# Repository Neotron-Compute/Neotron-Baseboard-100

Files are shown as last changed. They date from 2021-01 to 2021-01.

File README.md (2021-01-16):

# Neotron-Baseboard-100

The Neotron Baseboard 100 is an micro-ATX Neotron motherboard, with Neotron CPU Socket and 4x Neotron Expansion Slots.

You must fit a Neotron CPU card for this board to function (or attach a microcontroller dev-kit of your choice using jumper wires).

### Audio Codec

* Texas Instruments TLV320AIC23B
  * I²S + I²C interface
  * Amplified 32mW headphone output and line out
  * Microphone in and line in
  * TSSOP-28 package
* Triple 3.5mm TRS jack (Kycon STX-4335-5BGP-S1)
  * Headphone Out (green)
  * Line In (blue)
  * Microphone In (pink)
* AC'97 Pin Header
  * Headphone Out
  * Microphone In
* Extra line-level output pin header (e.g. for additional RCA audio jacks - operates in addition to 3.5mm headphone jack output)
* Internal line-level input pin header (e.g. for CD-ROM audio - disabled when line-in 3.5mm jack in-use)

### Super VGA output

* 15-pin D-Sub VGA interface
* 18-bit (6-6-6) RGB R2R DAC
* 3peak TPF133A or Texas Instruments THS7316 RGB video buffer
   * 36 MHz bandwidth - 1024x768@60Hz maximum
   * 6dB gain
   * Drives 75 ohm standard VGA interface
* I²C/DDC level shifter and EMC filter

### RS232 Interface

* Tx, Rx, RTS and CTS signals
* 3.3V TTL on the MCU side
* RS-232 signalling on a 9-pin D-Sub connector (or 10-pin IDC box header), wired DTE

### Board Management Controller

* ST Micro STM32F0 (STM32F030F4P6) microcontroller
  * 32-bit Arm Cortex-M0+ Core
  * 3.3V I/O
  * 8 KiB Flash
  * 4 KiB SRAM
  * TSSOP-20 package
* Controls two PS/2 ports
* Monitors 5V and 3.3V rails
* Controls system reset, soft-on and soft-off for main CPU
* Can the main 5V regulator on and off
* Runs from 3.3V stand-by regulator
* I²C interface (with dedicated IRQ line) with main CPU

| Pin | Name  | Peripheral | Function |
|:----|:---|:---|:---|
| 16  | VDD | N/A | 3.3V Digital Power |
| 5 | VDDA  | N/A | 3.3V Analog Power  |
| 15  | VSS | N/A | Ground |
| 1 | BOOT0 | BOOT0 | Boot Mode Select |
| 4 | NRST  | Reset | Reset BMC |
| 6 | PA0 | ADC0 | Monitor 3.3V rail  |
| 7 | PA1 | ADC0 | Monitor 5V rail |
| 8 | PA2 | USART1_TX  | Debug Log |
| 9 | PA3 | Output | Status LED |
| 10  | PA4 | Output | DC-DC Enable |
| 11  | PA5 | Output | System Reset |
| 12  | PA6 | Input | Reset Switch In |
| 13  | PA7 | Input | Power Switch In |
| 17  | PA9 | I2C0_SCL | Host comms |
| 18  | PA10  | I2C0_SDA | Host comms |
| 19  | PA13  | IO | PS/2 Data 1 |
| 20  | PA14  | IO | PS/2 Clock 1 |
| 14  | PB1 | Output | Host IRQ |
| 2 | PF0 | IO | PS/2 Data 0 |
| 3 | PF1 | IO | PS/2 Clock 0 |

### PS/2 Keyboard and Mouse

* Twin mini 6-pin DIN ports
* Controlled via Board Management Controller

### Power Supply

* Unregulated 12V (8V to 28V) input fused with a PTC at 2A
* 3A 5.0V main regulator (DC-DC switch-mode regulator module)
* 30mA 3.3V stand-by regulator (a micropower linear regulator)
* 1A 3.3V regulator (a high-power 1117 type linear regulator)
* Controlled by the Board Management Controller

### CPU Socket

The CPU can either be designed to solder direct to your particular motherboard design, or it can be fitted to a second PCB 'CPU card' which plugs into a socket on the motherboard. We have designed a special 80-pin socket pinout, which provides all the signals for required for the standard peripherals available in this design.

The socket is basically two 2x20 pin headers, placed 130 mil apart. This should give enough space to fit even a TQFP-176 microcontroller and some TSOP-54 SDRAM.

The pins are labelled in row.column fashion, i.e. 1.1 is top left, 1.20 is top right and 4.20 is bottom right.

```
 +----- Pin 1.1
 |
 v
+---------------------------------------+
|o o o o o o o o o o o o o o o o o o o o|
|o o o o o o o o o o o o o o o o o o o o|
+---------------------------------------+

+---------------------------------------+
|o o o o o o o o o o o o o o o o o o o o|
|o o o o o o o o o o o o o o o o o o o o|
+---------------------------------------+
                                       ^
                                       |
                         Pin 4.20 -----+
```

| Pin  | Function |
|:-----|:---|
| 1.1  | VGA_RED5 |
| 1.2  | VGA_RED4 |
| 1.3  | VGA_RED3 |
| 1.4  | VGA_RED2 |
| 1.5  | VGA_RED1 |
| 1.6  | VGA_RED0 |
| 1.7  | VGA_GREEN5 |
| 1.8  | VGA_GREEN4 |
| 1.9  | VGA_GREEN3 |
| 1.10 | VGA_GREEN2 |
| 1.11 | VGA_GREEN1 |
| 1.12 | VGA_GREEN0 |
| 1.13 | VGA_BLUE5 |
| 1.14 | VGA_BLUE4 |
| 1.15 | VGA_BLUE3 |
| 1.16 | VGA_BLUE2 |
| 1.17 | VGA_BLUE1 |
| 1.18 | VGA_BLUE0 |
| 1.19 | VGA_HSYNC |
| 1.20 | VGA_VSYNC |
| 2.1  | VGA_DDC_SDA |
| 2.2  | VGA_DDC_SCL |
| 2.3  | UART_RX |
| 2.4  | UART_TX |
| 2.7  | 3V3 |
| 2.8  | 3V3 |
| 2.9  | 3V3 |
| 2.10 | GND |
| 2.11 | GND |
| 2.12 | GND |
| 2.13 | AUDIO_BCLK_TO_CODEC  |
| 2.14 | AUDIO_DAT_TO_CODEC |
| 2.15 | AUDIO_LR_TO_CODEC |
| 2.16 | AUDIO_DAT_FROM_CODEC |
| 2.17 | AUDIO_LR_FROM_CODEC  |
| 2.18 | USB_EN |
| 2.19 | USB_D- |
| 2.20 | USB_D+ |
| 3.1  | I2C_SDA |
| 3.2  | I2C_SCL |
| 3.3  | UART_CTS |
| 3.4  | UART_RTS |
| 3.7  | GND |
| 3.8  | GND |
| 3.9  | GND |
| 3.10 | 5V |
| 3.11 | 5V |
| 3.12 | 5V |
| 3.13 | ~SPI_CS7 |
| 3.14 | ~SPI_CS6 |
| 3.15 | ~SPI_CS5 |
| 3.16 | ~SPI_CS4 |
| 3.17 | ~SPI_CS3 |
| 3.18 | ~SPI_CS2 |
| 3.19 | ~SPI_CS1 |
| 3.20 | ~SPI_CS0 |
| 4.1  | ~SDMMC_CARD_DETECT |
| 4.2  | ~SDMMC_WRITE_PROT |
| 4.3  | SDMMC_DAT2 |
| 4.4  | SDMMC_DAT3 |
| 4.5  | SDMMC_CMD |
| 4.6  | SDMMC_CLK |
| 4.7  | SDMMC_DAT0 |
| 4.8  | SDMMC_DAT1 |
| 4.9  | SPI_COPI |
| 4.10 | SPI_CIPO |
| 4.11 | SPI_CLK |
| 4.12 | ~RESET |
| 4.13 | ~IRQ7 |
| 4.14 | ~IRQ6 |
| 4.15 | ~IRQ5 |
| 4.16 | ~IRQ4 |
| 4.17 | ~IRQ3 |
| 4.18 | ~IRQ2 |
| 4.19 | ~IRQ1 |
| 4.20 | ~IRQ0 |

## Expansion

The (up-to) seven expansion sockets allow you to add on I²C or SPI based devices at a later date. Each provides a single chip-select and a single IRQ line - the motherboard design should ensure each socket gets a unique signal for each of these. Each expansion device should also contain a AT24C256 or similar EEPROM device. To allow these EEPROM devices to be scanned, each slot also contains three `EEPROM_ADDRESS` pins, tied to Vcc or GND in a unique combination. These should be connected through to the EEPROM address lines on your AT24C256, thus ensuring that each expansion card has its EEPROM at a unique address - 0x50 on Slot 0 through to a maximum possible 0x57 for Slot 7. Where your board has on-board devices, you should fit an AT24C256 EEPROM for each device so that the on-board devices can be discovered, exactly as if they were on an expansion card.

The expansion slot is a simple 2x10 header. We suggest the use of a TE card-edge connector, but you could equally use two 1x10 pin-headers if desired.

The pin functions are:

```
     SPI_COPI   1    2   GND
     SPI_CIPO   3    4   GND
      SPI_CLK   5    6   GND
      ~SPI_CS   7    8   ~IRQ
      I2C_SDA   9   10   I2C_SCL
 EEPROM_ADDR0   11  12   EEPROM_ADDR1
 EEPROM_ADDR2   13  14   ~RESET
           5V   15  16   5V
          3V3   17  18   3V3
          GND   19  20   GND
```

## Expansion Ideas

Why not design and build your own expansion card? You could try designing:

* A dual Atari/SEGA 9-pin Joypad Interface
* An Ethernet card, e.g. with an ENC28J60 SPI/Ethernet interface IC
* A Mikro Eletronika Click adaptor, allow many of the range of [Click board](https://www.mikroe.com/click) to be fitted
* A Wi-Fi/Bluetooth card, using an Espressif ESP32
* A second processor card - perhaps with a RISC-V microcontroller, or classic Zilog Z80
* An OPL2 or OPL3 based FM synthesiser card
* An ISA adaptor card (taking an ISA card at right-angles, i.e. parallel to the base board) - a simple microcontroller should be able to bit-bang the ISA bus at 8 MHz and offer an SPI peripheral interface to the Neotron Expansion Slot
* An IDE interface card, allowing 40-pin IDE Hard Disk Drives and CD-ROM drives to be used - this will be quite similar to an ISA bus adaptor
* A floppy drive controller card - either using an eSPI Super I/O chip, or connecting a legacy ISA bus floppy controller as per the ISA adaptor
* A video card for a second monitor output, perhaps based on the CPLD used in the [VGAtonic](https://hackaday.io/project/6309-vga-graphics-over-spi-and-serial-vgatonic)

## Changelog

See [CHANGELOG.md](./CHANGELOG.md) for a list of detailed changes.

## Licence

This schematic and PCB design is Copyright (c) The Neotron Developers.



This work is licensed under a [Creative Commons Attribution-ShareAlike 4.0 International License](http://creativecommons.org/licenses/by-sa/4.0/).

## Contribution Agreement

Unless you explicitly state otherwise, any contribution intentionally submitted for inclusion in the work by you, as defined in the Apache-2.0 license, shall be licensed as above, without any additional terms or conditions.

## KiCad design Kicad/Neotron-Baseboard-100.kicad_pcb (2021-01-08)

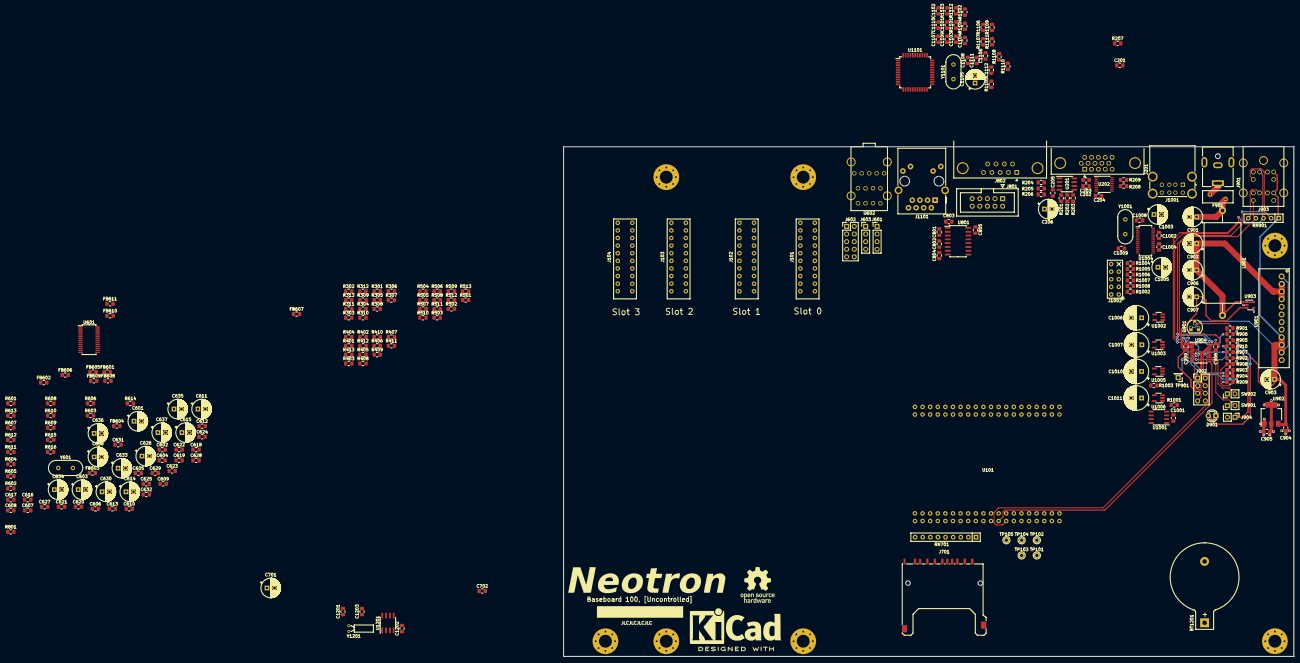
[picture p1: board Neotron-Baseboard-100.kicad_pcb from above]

Board: 4 copper layers, 243.8 x 170.2 mm, 257 parts (0 on the bottom side), 218 nets.

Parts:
BT1201: Coin Cell; BatteryHolder_Keystone_103_1x20mm
C201: 220n; C_0805_2012Metric_Pad1.15x1.40mm_HandSolder
C202, C203, C204, C205, C602, C604, C612, C613, C627, C702, C801, C802, C803, C804, C805, C904, C908, C909, C1001, C1002, C1004, C1106, C1107, C1108, C1109, C1110, C1201: 100n; C_0805_2012Metric_Pad1.15x1.40mm_HandSolder
C206, C601, C603, C611, C626, C633, C634, C635, C636, C637, C638, C701: 10u; CP_Radial_D6.3mm_P2.50mm
C605, C606, C620, C621: 470n; C_0805_2012Metric_Pad1.15x1.40mm_HandSolder
C607, C608, C609, C610, C616, C617, C618, C619, C622, C623, C624, C625, C632: DNF; C_0805_2012Metric_Pad1.15x1.40mm_HandSolder
C614, C615: 220u; CP_Radial_D6.3mm_P2.50mm
C628, C629: 22p; C_0805_2012Metric_Pad1.15x1.40mm_HandSolder
C630: 1u; CP_Radial_D6.3mm_P2.50mm
C631: 47p; C_0805_2012Metric_Pad1.15x1.40mm_HandSolder
C901, C902: 100u 50V; CP_Radial_D6.3mm_P2.50mm
C903: 22u; CP_Radial_D6.3mm_P2.50mm
C905: 1u; C_0805_2012Metric_Pad1.15x1.40mm_HandSolder
C906: 1u 50V; CP_Radial_D6.3mm_P2.50mm
C907, C1003, C1005: 4u7; CP_Radial_D6.3mm_P2.50mm
C1006, C1007, C1010, C1011: 120u; CP_Radial_D8.0mm_P3.50mm
C1008, C1009, C1103, C1104: 12p; C_0805_2012Metric_Pad1.15x1.40mm_HandSolder
C1101, C1102: 10n; C_0805_2012Metric_Pad1.15x1.40mm_HandSolder
C1105: 10u Low ESR; CP_Radial_D6.3mm_P2.50mm
C1111, C1112: 1n; C_0805_2012Metric_Pad1.15x1.40mm_HandSolder
C1202, C1203: 6p; C_0805_2012Metric_Pad1.15x1.40mm_HandSolder
D901: LED; LED_D3.0mm
F901: 32V 2A PTC; Fuse_BelFuse_0ZRE0016FF_L9.9mm_W3.8mm
FB601, FB602, FB603, FB604, FB605, FB606, FB608, FB609, FB610, FB611: 220R@100MHz; L_0805_2012Metric_Pad1.15x1.40mm_HandSolder
FB607: 600R@100MHz; L_0805_2012Metric_Pad1.15x1.40mm_HandSolder
H101, H102, H103, H104, H105, H106, H107: MountingHole_Pad; MountingHole_4.3mm_M4_Pad_Via
J101, J102, J103, J104: Neotron-Expansion-Slot
J201: DE15HD; DSUB-15-HD_Female_Horizontal_P2.29x1.98mm_EdgePinOffset3.03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
J601: Line Out; PinHeader_1x04_P2.54mm_Vertical
J602: AC'97 Audio Header; PinHeader_2x05_P2.54mm_Vertical
J603: CD Audio In; PinHeader_1x04_P2.54mm_Vertical
J701: SD_Card; SD_Kyocera_145638009211859+
J801: Conn_02x05; IDC-Header_2x05_P2.54mm_Vertical
J802: DB9_Male_MountingHoles; DSUB-9_Male_Horizontal_P2.77x2.84mm_EdgePinOffset7.70mm_Hou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
J901: Jack-DC; BarrelJack_CUI_PJ-063AH_Horizontal
J902: Conn_02x04_Odd_Even; PinHeader_2x04_P2.54mm_Vertical
J903: Double-mini-DIN-6; Double_mini-DIN_6
J904: Header; PinHeader_1x02_P2.54mm_Vertical
J1001: USB Ports External; CUI_UJ2-ADH-1-TH
J1002: USB Ports Internal; USB_Header
J1101: RJ45 MagJack; RJ45_Amphenol_RJMG1BD3B8K1ANR
L901: 22uH 6A; L_Axial_L26.7mm_D12.1mm_P35.00mm_Horizontal_Vishay_IHA-103
LOGO101: Neotron Logo; logo
LOGO102: Kicad Logo; KiCad-Logo2_12mm_SilkScreen
LOGO103: OSHW Logo; OSHW-Logo_11.4x12mm_SilkScreen
Q901: BC548; TO-92_HandSolder
R201, R202, R203: 75; R_0805_2012Metric_Pad1.15x1.40mm_HandSolder
R204, R205, R206, R613, R902, R903, R904, R906, R907, R908, R909, R1001, R1003, R1004, R1005, R1006, R1007, R1008: 10k; R_0805_2012Metric_Pad1.15x1.40mm_HandSolder
R207, R801, R1110: DNF; R_0805_2012Metric_Pad1.15x1.40mm_HandSolder
R208, R209: 1k5; R_0805_2012Metric_Pad1.15x1.40mm_HandSolder
R301, R302, R303, R304, R305, R306, R312, R401, R402, R403, R404, R405, R406, R412, R501, R502, R503, R504, R505, R506, R512: 24k 0.5%; R_0805_2012Metric_Pad1.15x1.40mm_HandSolder
R307, R308, R309, R310, R311, R407, R408, R409, R410, R411, R507, R508, R509, R510, R511: 12k 0.5%; R_0805_2012Metric_Pad1.15x1.40mm_HandSolder
R313, R413, R513: 3300; R_0805_2012Metric_Pad1.15x1.40mm_HandSolder
R601, R602: 100; R_0805_2012Metric_Pad1.15x1.40mm_HandSolder
R603, R604, R605, R606: 47k; R_0805_2012Metric_Pad1.15x1.40mm_HandSolder
R607, R608, R609, R610, R612: 4k7; R_0805_2012Metric_Pad1.15x1.40mm_HandSolder
R611: 2k2; R_0805_2012Metric_Pad1.15x1.40mm_HandSolder
R614, R615, R616: 2R2; R_0805_2012Metric_Pad1.15x1.40mm_HandSolder
R901: 2k; R_0805_2012Metric_Pad1.15x1.40mm_HandSolder
R905, R910: 1k; R_0805_2012Metric_Pad1.15x1.40mm_HandSolder
R1002: 2k7 1%; R_0805_2012Metric_Pad1.15x1.40mm_HandSolder
R1101, R1103, R1104, R1107: 49R9 1%; R_0805_2012Metric_Pad1.15x1.40mm_HandSolder
R1102, R1106: 10; R_0805_2012Metric_Pad1.15x1.40mm_HandSolder
R1105: 100k; R_0805_2012Metric_Pad1.15x1.40mm_HandSolder
R1108, R1109: 180; R_0805_2012Metric_Pad1.15x1.40mm_HandSolder
R1111: 1M; R_0805_2012Metric_Pad1.15x1.40mm_HandSolder
R1112: 12k4 1%; R_0805_2012Metric_Pad1.15x1.40mm_HandSolder
RN701: 8x10k; R_Array_SIP9
RN901: 2k7 x 4; R_Array_SIP5
SW901, SW902: SW_DIP_x01; PinHeader_1x02_P2.54mm_Vertical
TP101, TP102, TP103, TP104, TP105: TestPoint; TestPoint_THTPad_D2.0mm_Drill1.0mm
TP901: TestPoint; PinHeader_1x01_P2.54mm_Vertical
U101: Neotron-CPU; Neotron_CPU_Socket
U201: THS7316; SOIC-8_3.9x4.9mm_P1.27mm
U202: TPD7S019; SSOP-16_3.9x4.9mm_P0.635mm
U601: TLV320AIC23BPW; TSSOP-28_4.4x9.7mm_P0.65mm
U602: STX-4335-5BGP-S1
U801: ST3232CDR; SO-16_5.3x10.2mm_P1.27mm
U901: 5V DC-DC Module; K78xx-3AR3
U902: TLV1117 3.3V 1A; SOT-223-3_TabPin2
U903: MAX1615; SOT-23-5
U904: STM32F030F4Px; TSSOP-20_4.4x6.5mm_P0.65mm
U1001: AP2501; SO-8_3.9x4.9mm_P1.27mm
U1002, U1003, U1005, U1006: MIC2005A-2YM5; SOT-23-5_HandSoldering
U1004: XR22404CG28; SSOP-28_3.9x9.9mm_P0.635mm
U1101: ENC424J600; TQFP-44_10x10mm_P0.8mm
U1201: MCP7940; SOIC-8_3.9x4.9mm_P1.27mm
Y601, Y1001: 12M; Crystal_HC49-4H_Vertical
Y1101: 25M; Crystal_HC49-4H_Vertical
Y1201: 32,768 Hz; Crystal_DS26_D2.0mm_L6.0mm_Horizontal

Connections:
+3.3VP: C907.1, C908.1, C909.1, J902.5, U903.3, U904.5, U904.16
+3V3: C204.2, C205.2, C206.2, C701.1, C702.1, C805.2, C905.1, C1106.1, C1107.1, C1108.1, C1109.1, C1110.1, C1111.1, C1112.1, C1201.1, FB608.2, FB610.2, J101.17, J101.18, J102.11, J102.17, J102.18, J103.12, J103.17, J103.18, J104.11, J104.12, J104.17, J104.18, J701.4, R908.1, R1001.1, R1003.1, R1101.2, R1102.1, R1103.1, R1104.2, R1105.1, R1106.1, R1107.1, RN701.1, U101.2.7, U101.2.8, U101.2.9, U201.4, U202.7, U801.16, U902.2, U1101.4, U1101.12, U1101.15, U1101.18, U1101.44, U1201.8
+5V: C202.2, C203.2, C903.1, C904.1, C1001.1, FB609.2, J101.15, J101.16, J102.15, J102.16, J103.15, J103.16, J104.15, J104.16, J201.9, J903.4, J903.10, R208.1, R209.1, R902.1, RN901.1, U101.3.10, U101.3.11, U101.3.12, U202.1, U202.2, U901.4, U902.3, U1001.2, U1001.3
+BATT: BT1201.1, U1201.3
/Audio/3V3_ANALOG: C601.1, C602.1, C603.1, C604.1, C634.1, R614.1, U601.8, U601.14
/Audio/3V3_DIGITAL: C611.1, C612.1, C613.1, C638.1, R616.1, U601.1, U601.27
/Audio/5V0_ANALOG: C636.1, J602.7, R615.1
/Audio/AUDIO_BIT_CLK_TO_CODEC: U101.2.13, U601.3
/Audio/AUDIO_DAT_FROM_CODEC: U101.2.16, U601.6
/Audio/AUDIO_DAT_TO_CODEC: U101.2.14, U601.4
/Audio/AUDIO_LR_FROM_CODEC: U101.2.17, U601.7
/Audio/AUDIO_LR_TO_CODEC: U101.2.15, U601.5
/Audio/BIASOUT: R611.2, U601.17
/Audio/CDInL: J603.1, U602.34
/Audio/CDInR: J603.4, U602.33
/Audio/FrontHPL: C617.2, FB603.1, J602.9
/Audio/FrontHPR: C619.2, FB604.1, J602.5
/Audio/FrontMicL: J602.1, U602.4
/Audio/FrontMicR: J602.3, U602.3
/Audio/LineL: C608.2, FB601.1, J601.1
/Audio/LineR: C610.2, FB602.1, J601.4
/Audio/MICIN: R612.1, U601.18
/Audio/RearHPL: J602.10, U602.25
/Audio/RearHPR: J602.6, U602.22
/Audio/RearInL: C623.2, FB605.1, U602.35
/Audio/RearInR: C625.2, FB606.1, U602.32
/Audio/RearMicL: C632.2, FB607.1, R613.2, U602.2, U602.5
/B0: R501.1, U101.1.18
/B1: R502.1, U101.1.17
/B2: R503.1, U101.1.16
/B3: R504.1, U101.1.15
/B4: R505.1, U101.1.14
/B5: R506.1, U101.1.13
/G0: R401.1, U101.1.12
/G1: R402.1, U101.1.11
/G2: R403.1, U101.1.10
/G3: R404.1, U101.1.9
/G4: R405.1, U101.1.8
/G5: R406.1, U101.1.7
/I2C_SCL: J101.9, J102.9, J103.9, J104.9, J902.1, U101.3.2, U601.24, U1201.6
/I2C_SDA: J101.10, J102.10, J103.10, J104.10, J902.3, U101.3.1, U601.23, U1201.5
/Power Supply/BOOT0: J902.7, R907.1, U904.1
/Power Supply/DC_ON: R901.2, R906.1, U904.10
/Power Supply/MON_3V3: R908.2, R909.1, U904.6
/Power Supply/MON_5V: R903.2, R904.1, U904.7
/Power Supply/PS2_CLK0: J903.5, RN901.2, U904.3
/Power Supply/PS2_CLK1: J903.11, RN901.4, U904.20
/Power Supply/PS2_DAT0: J903.1, RN901.3, U904.2
/Power Supply/PS2_DAT1: J903.7, RN901.5, U904.19
/Power Supply/SCL_U1TX: J902.2, U904.17
/Power Supply/SDA_U1RX: J902.4, U904.18
/Power Supply/USART1_TX: TP901.1, U904.8
/Power Supply/~BMC_RST: J902.6, U904.4
/Power Supply/~BUTTON_PWR: SW902.2, U904.13
/Power Supply/~BUTTON_RST: SW901.2, U904.12
/Power Supply/~PSU_EN: Q901.1, U901.1
/Power Supply/~STATUS_LED: R905.1, R910.1, U904.9
/R0: R301.1, U101.1.6
/R1: R302.1, U101.1.5
/R2: R303.1, U101.1.4
/R3: R304.1, U101.1.3
/R4: R305.1, U101.1.2
/R5: R306.1, U101.1.1
/SD Card/CLK: J701.5, RN701.5, U101.4.5
/SD Card/CMD: J701.2, RN701.4, U101.4.6
/SD Card/DAT0: J701.7, RN701.6, U101.4.4
/SD Card/DAT1: J701.8, RN701.7, U101.4.3
/SD Card/DAT2: J701.9, RN701.2, U101.4.8
/SD Card/DAT3: J701.1, RN701.3, U101.4.7
/SD Card/~CARD_DETECT: J701.10, RN701.8, U101.4.1
/SD Card/~WRITE_PROTECT: J701.11, RN701.9, U101.4.2
/SPI_CIPO: J101.3, J102.3, J103.3, J104.3, U101.4.10, U1101.35
/SPI_CLK: J101.5, J102.5, J103.5, J104.5, U101.4.11, U1101.37
/SPI_COPI: J101.1, J102.1, J103.1, J104.1, U101.4.9, U1101.36
/Serial/RS232_CTS_IN: J801.8, J802.8, U801.8
/Serial/RS232_CTS_TO_MCU: U101.3.3, U801.9
/Serial/RS232_RTS_FROM_MCU: U101.3.4, U801.10
/Serial/RS232_RTS_OUT: J801.7, J802.7, U801.7
/Serial/RS232_RX_IN: J801.2, J802.2, U801.13
/Serial/RS232_RX_TO_MCU: U101.2.3, U801.12
/Serial/RS232_TX_FROM_MCU: U101.2.4, U801.11
/Serial/RS232_TX_OUT: J801.3, J802.3, U801.14
/USB/USBD1+: J1001.2, U1004.11
/USB/USBD1-: J1001.3, U1004.10
/USB/USBD2+: J1001.6, U1004.9
/USB/USBD2-: J1001.7, U1004.8
/USB/USBD3+: J1002.2, U1004.7
/USB/USBD3-: J1002.3, U1004.6
/USB/USBD4+: J1002.6, U1004.5
/USB/USBD4-: J1002.7, U1004.4
/USB/USBD+: U101.2.20, U1004.16
/USB/USBD-: U101.2.19, U1004.15
/USB/USB_3V3: C1002.1, C1003.1, R1004.1, R1005.1, R1006.1, R1007.1, U1004.21
/USB/USB_5V: C1004.1, C1005.1, U1001.6, U1001.7, U1002.1, U1003.1, U1004.20, U1005.1, U1006.1
/USB/~ENABLE: R1001.2, U101.2.18, U1001.4
/Video/BLUE_ANA: R206.2, R506.2, R511.1, R513.1, U201.3
/Video/DDC_SCL: U101.2.2, U202.11
/Video/DDC_SDA: U101.2.1, U202.10
/Video/GREEN_ANA: R205.2, R406.2, R411.1, R413.1, U201.2
/Video/HSYNC: U101.1.19, U202.15
/Video/RED_ANA: R204.2, R306.2, R311.1, R313.1, U201.1
/Video/VGA_BLU: J201.3, R203.1, U202.5
/Video/VGA_DDC_SCL: J201.15, R209.2, U202.12
/Video/VGA_DDC_SDA: J201.12, R208.2, U202.9
/Video/VGA_GRN: J201.2, R202.1, U202.4
/Video/VGA_HSYNC: J201.13, U202.16
/Video/VGA_RED: J201.1, R201.1, U202.3
/Video/VGA_VSYNC: J201.14, U202.14
/Video/VSYNC: U101.1.20, U202.13
/~CS0: J101.7, U101.3.20
/~CS1: J102.7, U101.3.19
/~CS2: J103.7, U101.3.18
/~CS3: J104.7, U101.3.17
/~CS4: U101.3.16, U1101.34
/~CS5: TP102.1, U101.3.15
/~CS6: TP104.1, U101.3.14
/~CS7: TP105.1, U101.3.13
/~IRQ0: J101.8, U101.4.20
/~IRQ1: J102.8, U101.4.19
/~IRQ2: J103.8, U101.4.18
/~IRQ3: J104.8, U101.4.17
/~IRQ4: R1105.2, U101.4.16, U1101.24
/~IRQ5: TP101.1, U101.4.15
/~IRQ6: TP103.1, U101.4.14
/~IRQ7: U101.4.13, U904.14
/~RESET: J101.14, J102.14, J103.14, J104.14, U101.4.12, U904.11
GND: BT1201.2, C201.1, C202.1, C203.1, C204.1, C205.1, C206.1, C611.2, C612.2, C613.2, C628.1, C629.2, C633.2, C634.2, C635.2, C636.2, C701.2, C702.2, C803.1, C804.1, C805.1, C901.2, C902.2, C903.2, C904.2, C905.2, C906.2, C907.2, C908.2, C909.2, C1001.2, C1002.2, C1003.2, C1004.2, C1005.2, C1006.2, C1007.2, C1008.2, C1009.2, C1010.2, C1011.2, C1101.2, C1102.2, C1103.2, C1104.2, C1105.2, C1106.2, C1107.2, C1108.2, C1109.2, C1110.2, C1111.2, C1112.2, C1201.2, C1202.2, C1203.2, D901.1, FB611.1, H101.1, H102.1, H103.1, H104.1, H105.1, H106.1, H107.1, J101.2, J101.4, J101.6, J101.11, J101.12, J101.13, J101.19, J101.20, J102.2, J102.4, J102.6, J102.12, J102.13, J102.19, J102.20, J103.2, J103.4, J103.6, J103.11, J103.13, J103.19, J103.20, J104.2, J104.4, J104.6, J104.13, J104.19, J104.20, J201.5, J201.6, J201.7, J201.8, J201.10, J701.3, J701.6, J701.12, J701.13, J801.5, J802.5, J901.2, J902.8, J903.3, J903.9, J904.2, J1001.4, J1001.8, J1001.9, J1002.4, J1002.8, J1002.9, J1101.L2, J1101.L3, J1101.R8, Q901.3, R204.1, R205.1, R206.1, R207.1, R312.2, R313.2, R412.2, R413.2, R512.2, R513.2, R801.2, R904.2, R906.2, R907.2, R909.2, R1002.2, R1008.2, R1110.2, R1112.2, SW901.1, SW902.1, U101.2.10, U101.2.11, U101.2.12, U101.3.7, U101.3.8, U101.3.9, U201.5, U202.6, U601.22, U601.28, U801.15, U901.3, U902.1, U903.2, U903.4, U904.15, U1001.1, U1002.2, U1003.2, U1004.1, U1005.2, U1006.2, U1101.1, U1101.13, U1101.14, U1101.19, U1101.22, U1101.33, U1101.42, U1201.4
GNDA: C601.2, C602.2, C603.2, C604.2, C607.1, C608.1, C609.1, C610.1, C616.1, C617.1, C618.1, C619.1, C622.1, C623.1, C624.1, C625.1, C626.2, C627.2, C631.1, C632.1, C637.2, C638.2, FB611.2, J601.2, J601.3, J602.2, J602.4, J603.2, J603.3, R603.2, R604.1, R605.2, R606.1, R609.2, R610.1, R613.1, U601.11, U601.15, U602.1
unnamed: C201.2, U202.8
unnamed: C605.1, U601.12
unnamed: C605.2, R601.2
unnamed: C606.1, U601.13
unnamed: C606.2, R602.2
unnamed: C607.2, FB601.2, R601.1, R604.2
unnamed: C609.2, FB602.2, R602.1, R603.1
unnamed: C614.1, U601.9
unnamed: C614.2, C616.2, FB603.2, R606.2
unnamed: C615.1, U601.10
unnamed: C615.2, C618.2, FB604.2, R605.1
unnamed: C620.1, U601.20
unnamed: C620.2, R607.2, R610.2
unnamed: C621.1, U601.19
unnamed: C621.2, R608.2, R609.1
unnamed: C622.2, FB605.2, R607.1
unnamed: C624.2, FB606.2, R608.1
unnamed: C626.1, C627.1, U601.16
unnamed: C628.2, U601.25, Y601.1
unnamed: C629.1, U601.26, Y601.2
unnamed: C630.1, R612.2
unnamed: C630.2, C631.2, FB607.2, R611.1
unnamed: C633.1, FB608.1, R614.2
unnamed: C635.1, FB609.1, R615.2
unnamed: C637.1, FB610.1, R616.2
unnamed: C801.1, U801.3
unnamed: C801.2, U801.1
unnamed: C802.1, U801.4
unnamed: C802.2, U801.5
unnamed: C803.2, U801.2
unnamed: C804.2, U801.6
unnamed: C901.1, F901.1, L901.1
unnamed: C902.1, C906.1, L901.2, U901.2, U903.1, U903.5
unnamed: C1006.1, J1001.1, U1002.5
unnamed: C1007.1, J1001.5, U1003.5
unnamed: C1008.1, U1004.2, Y1001.2
unnamed: C1009.1, U1004.3, Y1001.1
unnamed: C1010.1, J1002.1, U1005.5
unnamed: C1011.1, J1002.5, U1006.5
unnamed: C1101.1, J1101.R4, R1102.2
unnamed: C1102.1, J1101.R5, R1106.2
unnamed: C1103.1, R1111.2, Y1101.1
unnamed: C1104.1, U1101.3, Y1101.2
unnamed: C1105.1, U1101.43
unnamed: C1202.1, U1201.2, Y1201.2
unnamed: C1203.1, U1201.1, Y1201.1
unnamed: D901.2, R905.2
unnamed: F901.2, J901.1
unnamed: J201.0, R207.2
unnamed: J802.0, R801.1
unnamed: J904.1, R910.2
unnamed: J1101.13, R1110.1
unnamed: J1101.L1, R1109.2
unnamed: J1101.L4, R1108.2
unnamed: J1101.R1, R1101.1, U1101.20
unnamed: J1101.R2, R1103.2, U1101.21
unnamed: J1101.R3, R1104.1, U1101.16
unnamed: J1101.R6, R1107.2, U1101.17
unnamed: Q901.2, R901.1
unnamed: R201.2, U201.8
unnamed: R202.2, U201.7
unnamed: R203.2, U201.6
unnamed: R301.2, R307.2, R312.1
unnamed: R302.2, R307.1, R308.2
unnamed: R303.2, R308.1, R309.2
unnamed: R304.2, R309.1, R310.2
unnamed: R305.2, R310.1, R311.2
unnamed: R401.2, R407.2, R412.1
unnamed: R402.2, R407.1, R408.2
unnamed: R403.2, R408.1, R409.2
unnamed: R404.2, R409.1, R410.2
unnamed: R405.2, R410.1, R411.2
unnamed: R501.2, R507.2, R512.1
unnamed: R502.2, R507.1, R508.2
unnamed: R503.2, R508.1, R509.2
unnamed: R504.2, R509.1, R510.2
unnamed: R505.2, R510.1, R511.2
unnamed: R902.2, R903.1
unnamed: R1002.1, U1004.14
unnamed: R1003.2, U1002.4, U1003.4, U1004.26, U1005.4, U1006.4
unnamed: R1004.2, U1004.17
unnamed: R1005.2, U1004.19
unnamed: R1006.2, U1004.18
unnamed: R1007.2, U1004.27
unnamed: R1008.1, U1004.22
unnamed: R1108.1, U1101.10
unnamed: R1109.1, U1101.9
unnamed: R1111.1, U1101.2
unnamed: R1112.1, U1101.11
unnamed: U1002.3, U1003.3, U1004.25, U1005.3, U1006.3

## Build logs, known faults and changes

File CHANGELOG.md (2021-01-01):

# Changelog

## Unreleased Changes

* Bring in Neotron Common at 0.2.0
* Start basic schematic

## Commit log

2021-01-01 Create skeleton Kicad file.
    [Neotron-Baseboard-100.kicad_pcb, Neotron-Baseboard-100.sch]
2021-01-01 Imported top-level schematic from common.
    [Neotron-Baseboard-100.sch]
2021-01-01 Bring over basic PCB shape.
    Dropped down to "short micro-ATX" - 9.6" across, 6.7" high.
    [Neotron-Baseboard-100.kicad_pcb]
2021-01-01 Wiring up top sheet.
    [Neotron-Baseboard-100.sch]
2021-01-01 Updated common to 0.4.0 and added some part numbers.
    [Neotron-Baseboard-100.kicad_pcb, Neotron-Baseboard-100.sch]
2021-01-02 Working on PSU layout.
    [Neotron-Baseboard-100.kicad_pcb]
2021-01-03 Working on laying out USB hub.
    [Neotron-Baseboard-100.kicad_pcb]
2021-01-03 Wired up UART and expansion slots.
    [Neotron-Baseboard-100.kicad_pcb]
2021-01-07 Updating to common 0.5.0
    [Neotron-Baseboard-100.kicad_pcb, Neotron-Baseboard-100.sch]
2021-01-08 Added I2C addresses.
    [Neotron-Baseboard-100.sch]
2021-01-08 Updated to v0.6.0
    Started re-laying out PSU
    [Neotron-Baseboard-100.kicad_pcb]

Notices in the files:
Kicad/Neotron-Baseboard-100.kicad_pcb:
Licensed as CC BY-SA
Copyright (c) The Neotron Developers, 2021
